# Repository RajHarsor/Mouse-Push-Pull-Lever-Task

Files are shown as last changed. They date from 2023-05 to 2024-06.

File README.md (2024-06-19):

# Getting Started

For learning how to start up a task with a already made box, please visit the [Getting Started](https://github.com/RajHarsor/Mouse-Push-Pull-Lever-Task/wiki/Getting-Started) page on the wiki.

# Contact
For any questions or concerns, please contact Raj Harsora at rdh92@scarletmail.rutgers.edu

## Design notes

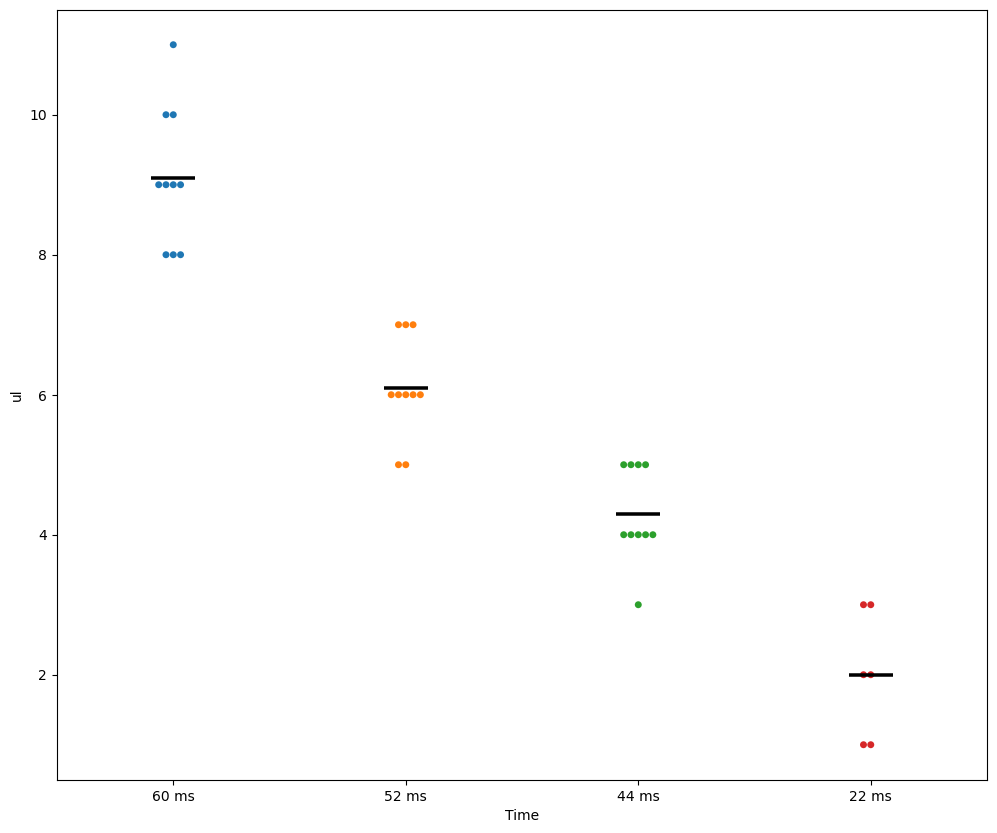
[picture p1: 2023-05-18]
Solenoid Equation Calculations/Figures/Figure.png

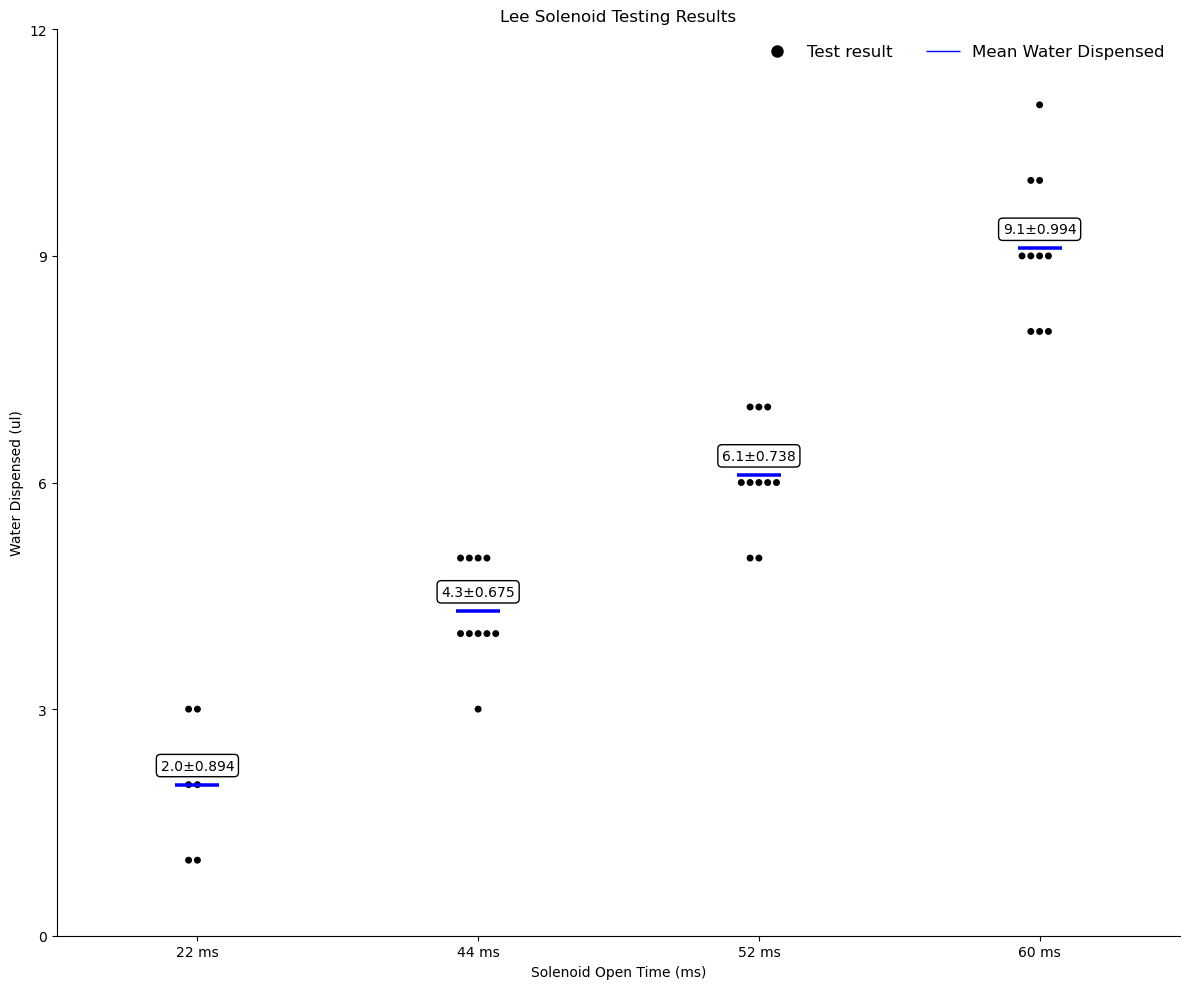
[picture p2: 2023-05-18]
Solenoid Equation Calculations/Figures/SolenoidFigure.png

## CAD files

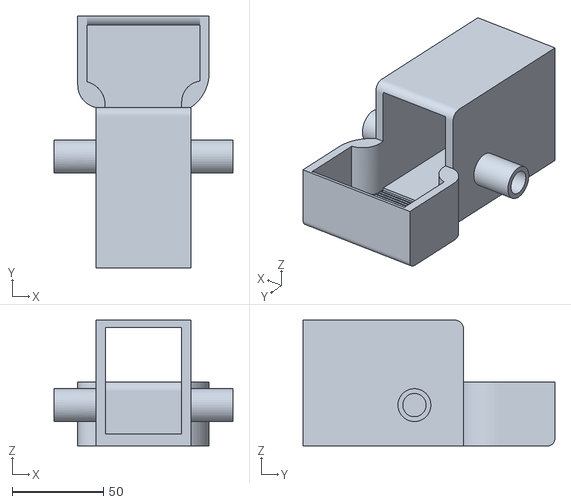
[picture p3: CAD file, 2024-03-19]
3D Print Files/MouseHolderCup.stl
98.1 x 138.0 x 69.0

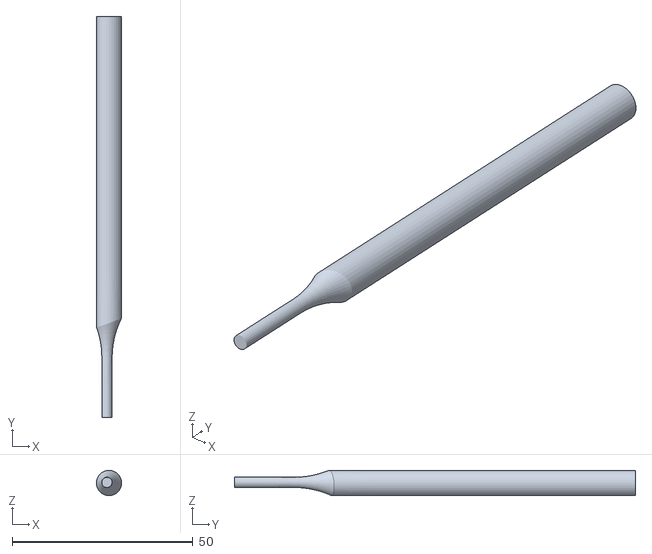
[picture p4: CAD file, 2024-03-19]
3D Print Files/LeverNew.stl
6.99 x 111.0 x 6.99

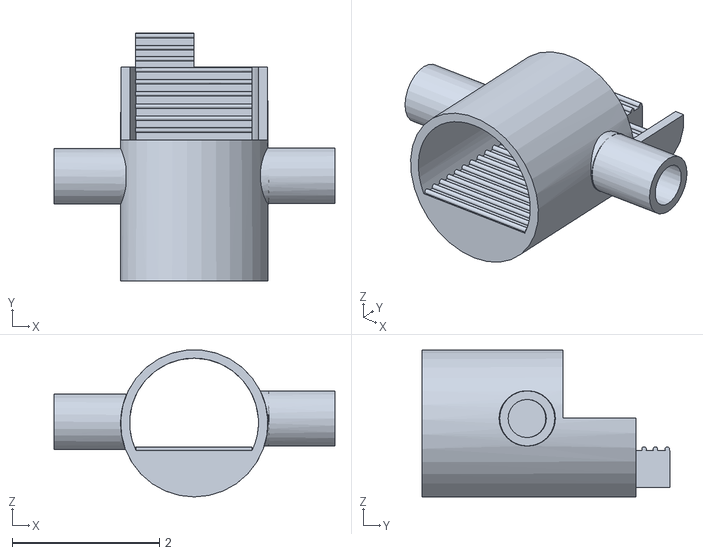
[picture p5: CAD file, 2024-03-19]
3D Print Files/Short mouse tube with open top - left.stl
3.82 x 3.37 x 2.00

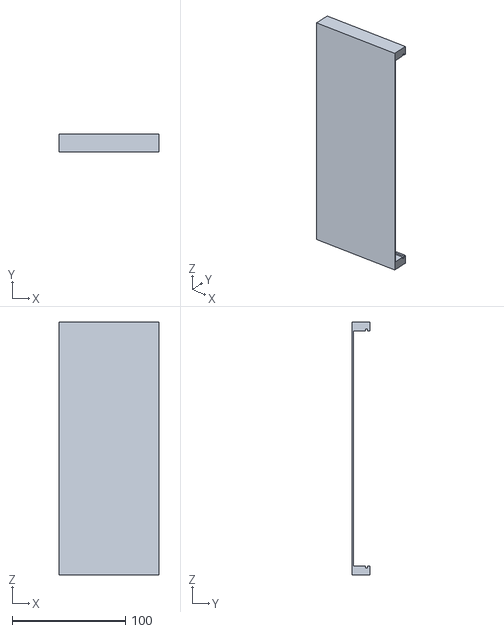
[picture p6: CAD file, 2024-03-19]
3D Print Files/Treedix Light Matrix Holder v2.stl
88.5 x 15.5 x 223.0

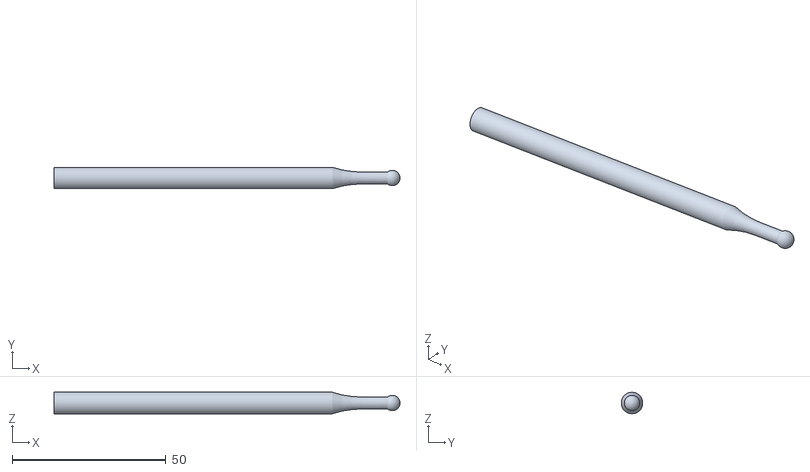
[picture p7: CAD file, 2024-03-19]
3D Print Files/Stick.stl
112.5 x 6.99 x 7.00

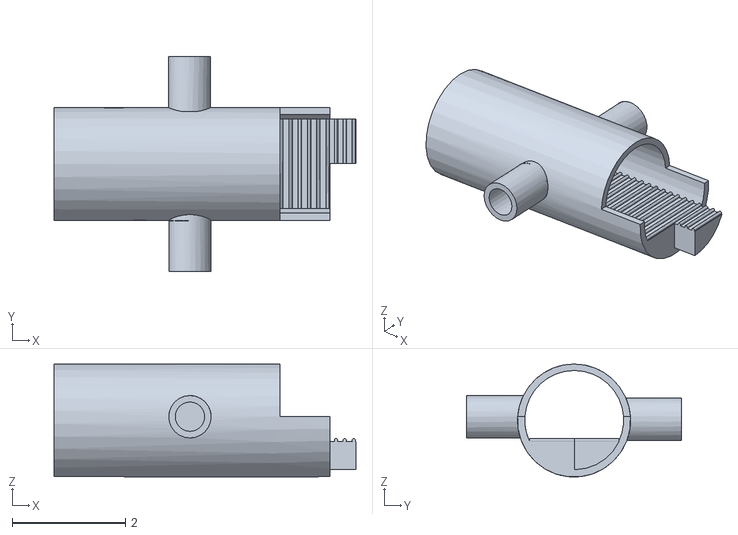
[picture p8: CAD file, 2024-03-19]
3D Print Files/Long mouse tube with open top - left.stl
5.34 x 3.80 x 2.00

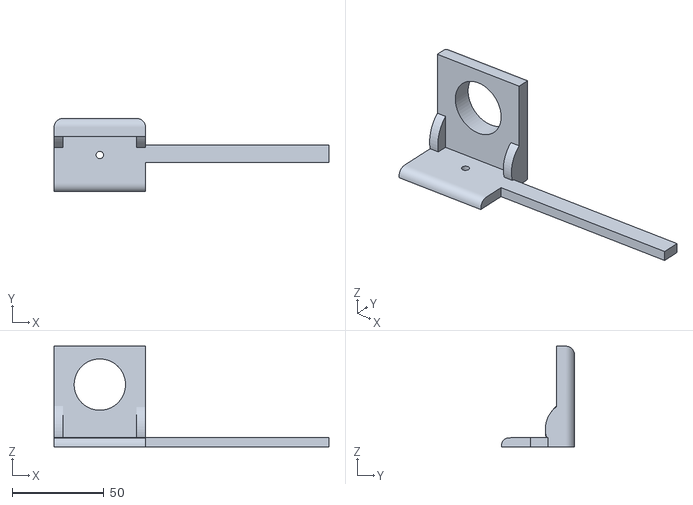
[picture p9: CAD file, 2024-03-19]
3D Print Files/JoystickReelHolder.stl
150.0 x 40.0 x 55.0

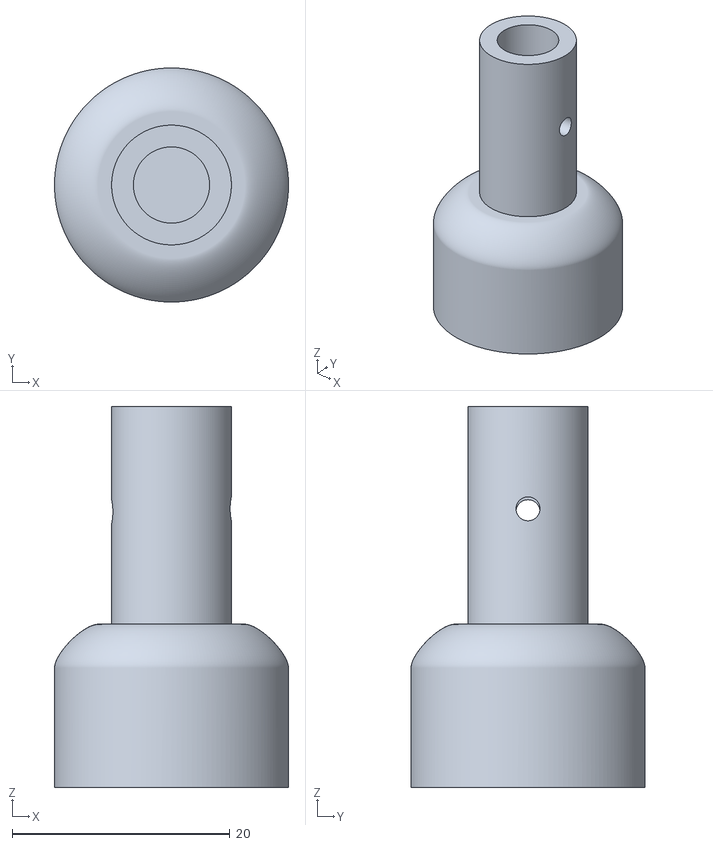
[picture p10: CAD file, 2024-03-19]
3D Print Files/Stick holder.stl
21.5 x 21.5 x 35.0

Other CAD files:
3D Print Files/LeverNew.f3d
3D Print Files/MouseHolderCup.f3d
3D Print Files/Treedix Light Matrix Holder v2.f3d

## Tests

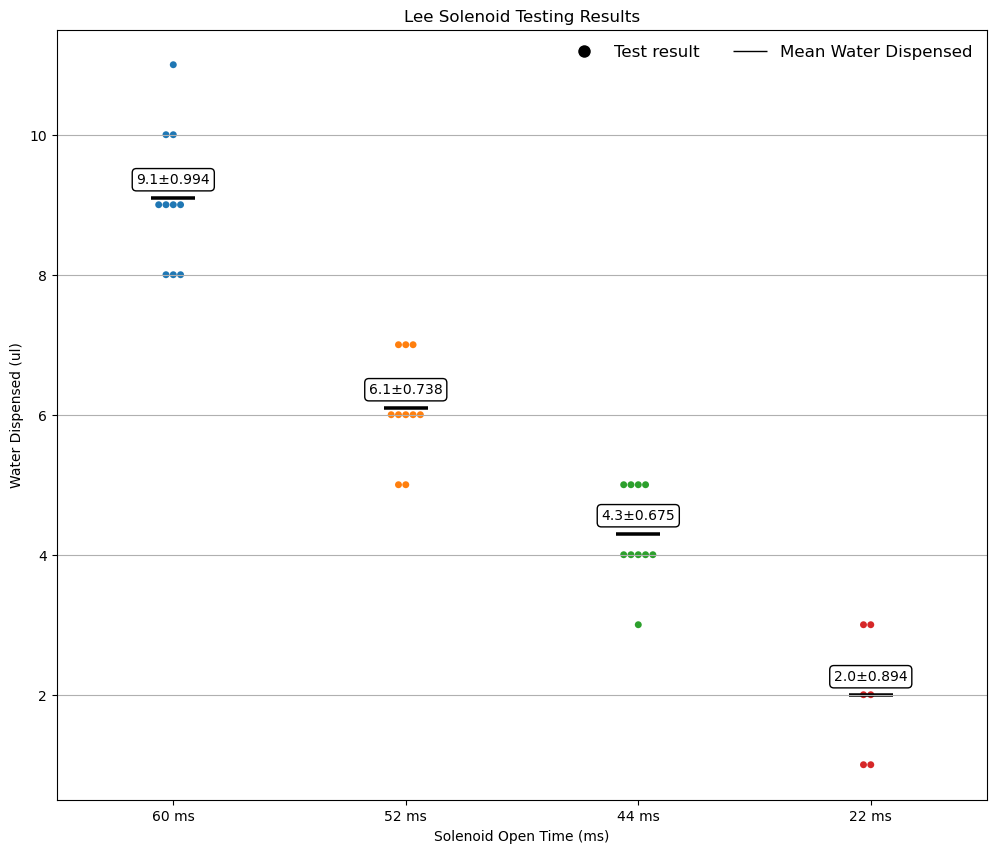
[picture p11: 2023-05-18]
Solenoid Equation Calculations/Figures/LeeSolenoidTestingFigureFinal.png

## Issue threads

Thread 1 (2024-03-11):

Adding button for water dispensing

RajHarsor, 2024-03-11:
To ensure a mouse gets water in the first movement, the tube must be completely filled up. Right now, this is a manual process. A button with an [attachInturrept()](https://www.arduino.cc/reference/en/language/functions/external-interrupts/attachinterrupt/) should be configured within the code to open the solenoid upon the button being pressed.

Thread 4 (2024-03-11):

Fix lick sensor

RajHarsor, 2024-03-11:
I had it working at one point but then it broke. Also, the speed is not the best (according to Masashi) and therefore, we might need to get another faster one and hook it up.

RajHarsor, 2024-05-08:
Temp fix _sometimes_ is simply reuploading the Joystick Code

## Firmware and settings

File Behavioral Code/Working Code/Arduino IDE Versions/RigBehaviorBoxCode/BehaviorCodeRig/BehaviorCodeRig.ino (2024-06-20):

/* #region DEPENDENCIES*/
#include <Arduino.h>
#include <vector>
#include <string>
#include <map>
#include <FastLED.h>
#include "parse_scripts.h"
#include "light_configs.h"
#include "solenoid_open_time.h"
#include "hold_time_mod_visual.h"
#include "hold_time_visual_punishment.h"
#include "reaction_time_mod_visual.h"
#include "WN_punishment.h"
#include "punishment_time_visual_mod.h"
#include "isi_delay_mod_visual.h"
#include "cue_evoked_sound.h"

/* #endregion */

/* #region PIN SETUPS */
#define VRX_PIN A0   // Arduino pin connected to VRX pin (aka Analog Pin A0), this is the blue cable
#define VRY_PIN A1   // Arduino pin connected to VRY pin (aka Analog Pin A1), this is the red cable
#define Solenoid 4   // Water Solenoid will be connected to Digital Pin 4
#define Puff 10      // Air solenoid for blowing air in the face of the mouse will be connected to Pin 5
#define REST_PIN 33  // Rest Pin will be connected to Digital Pin 33 on Behavior Teensy and Coordinate Teensy
#define PUSH_PIN 34  // Push Pin will be connected to Digital Pin 34 on Behavior Teensy and Coordinate Teensy
#define PULL_PIN 35  // Pull Pin will be connected to Digital Pin 35 on Behavior Teensy and Coordinate Teensy
/* #endregion */

/* #region LED Array Set Up*/
//Parameters
#define NUM_LEDS 48  //number of LEDs total
#define BRIGHTNESS 1

// Set up
#define DATA_PIN 8
#define CLOCK_PIN 14
//#define NUM_LEDS 48  //number of LEDs total
#define NUM_LEDS 64 //for the 8x8 matrix

CRGB leds[NUM_LEDS];  //define the array of LEDs

/* Array Set up (WS2012B) 48 LEDs

0  1  2  3  4  5
6  7  8  9  10 11
12 13 14 15 16 17
18 19 20 21 22 23
24 25 26 27 28 29
30 31 32 33 34 35
36 37 38 39 40 41
42 43 44 45 46 47
*/

/* #endregion */

/* #region BEHAVIOR VARIBALES CONST */
int totalTrials = 1000000;
int trialNumber = 1;
int decision;
int positionA = 0;
int positionB = 0;
int CorrectCounter = 0;
int SOpenTime1;

/* #endregion */

/* #region Timer Variables */
unsigned long currentMillis = 0;
int reactionTime;
#define timerMillis millis() - currentMillis
unsigned long startTime;

/* #endregion */

void setup() {
  delay(2000);
  /* #region Pins + Serial */
  Serial.begin(115200);
  Serial1.begin(9600);
  pinMode(Solenoid, OUTPUT);
  pinMode(Puff, OUTPUT);      // Sets the puff pin as an output
  pinMode(29, OUTPUT);        // Sets pin 29 as an output, if this pin is high it prints on the Coordinate Teensy that the current state is the rest state
  pinMode(30, OUTPUT);        // Sets pin 30 as an output, if this pin is high it prints on the Coordinate Teensy that the current state is the push/pull or push/down state
  pinMode(31, OUTPUT);        // Sets pin 31 as an output, if this pin is high it prints on the Coordinate Teensy that the current state is that the solenoid is open
  pinMode(32, OUTPUT);        // Sets pin 32 as an output, if this pin is high it prints on the Coordinate Teensy that the current state is that the ISI delay is occurring
  pinMode(28, OUTPUT);        // Set pin 28 as an output, if this pin is high it prints on the Coordinate Teensy that the current state is punishment
  pinMode(25, OUTPUT);
  pinMode(REST_PIN, INPUT);                             // Sets the rest pin as an input, if the mouse is in the rest coordinate range, the coordinate Teensy will set this pin high to tell the Behavior Teensy
  pinMode(PULL_PIN, INPUT);                             // Sets the pull pin as an input, if the mouse is in the pull coordinate range, the coordinate Teensy will set this pin high to tell the Behavior Teensy
  pinMode(PUSH_PIN, INPUT);                             // Sets the push pin as an input, if the mouse is in the push coordinate range, the coordinate Teensy will set this pin high to tell the Behavior Teensy                          // Probably useless
  randomSeed(analogRead(9));                            // Needed for random number generator for ISI Delay
  FastLED.addLeds<NEOPIXEL, DATA_PIN>(leds, NUM_LEDS);  // Sets up the light array
  FastLED.setBrightness(BRIGHTNESS);                    // Sets the brightness of the light array
  /* #endregion */
  Serial.println("What type of program would you like?");
  Serial.println("Type 1 for Visual Task");
  Serial.println("Type 2 for Auditory Task");
  parseProgramTypeInput();
  Serial.print(programType);
  switch (programType) {
    case 1: // visual task
      Serial.println("Pick the Stage (1-4)");
      parseVisualStage();
      break;
    case 2:
      Serial.println("What type of Motor Task do you want to do?");
      Serial.println("Type 1 for Cue-Evoked Task (Preset)");
      Serial.println("Type 2 for Cue-Evoked Task (Custom)");
      Serial.println("Type 3 for Single Direction Optogenetic Task");
      parseMotorTaskType();
      break;
  }
}

void loop() {
    // Rest position block
    currentMillis = millis();
    digitalWrite(29, HIGH);
    if (programType == 1) {
      holdTimeVisualTask();
    }
    while (timerMillis <= holdTime) {
      if (digitalRead(REST_PIN) == HIGH) {
        continue;
      } else {
        if (programType == 1) {
          holdTimeVisualPunishment();
        }
        currentMillis = millis();
        continue;
      }
    }
    digitalWrite(29, LOW);   // Tells the coordinate Teensy that the current state is not the rest state anymore
    digitalWrite(30, HIGH);  // Tells the coordinate Teensy that the current state is the push/pull or push/down state
    if (programType == 1) {
      reactionTimeWindowModVisual(); // modify the reaction time window if necessary
      lightArrayModifier(); // modify the percentages of light array options
      turnOnTheLights(); // turn on the appropriate light array
      digitalWrite(18, HIGH);
      }
    if (programType == 2) {
      play12kHzSound(soundCueDuration);
    }
    if (digitalRead(REST_PIN) != HIGH) {
      loop();
    }
    currentMillis = millis(); // start the reaction time window timer
    startTime = millis(); // start the reaction time timer
    while (timerMillis <= timeOutTime) {
      if (digitalRead(PUSH_PIN) == HIGH) {
          decision = 1; // push
          break;
        }
      if (digitalRead(PULL_PIN) == HIGH) {
          decision = 2; // pull
          break;
        } else {
          decision = 0; // punishment
        }
    }
    reactionTime = millis() - startTime; // calculate the reaction time
    lightsOff(); // turn off the lights - this can be in the motor task as well (doesn't hurt)
    digitalWrite(18, LOW);
    digitalWrite(30, LOW);  // Tells the coordinate Teensy that the current state is not the push/pull or push/down state anymore
    // Decision Results block //
    /* #region Visual Task Rewards */
    if (programType == 1) {
      switch (visualStage) {
        case 1:
          if (decision == 1) {
            positionA++;
            digitalWrite(31, HIGH);
            digitalWrite(Solenoid, HIGH);
            solenoidOpenTime();
            digitalWrite(Solenoid, LOW);
            digitalWrite(31, LOW);
            break;
          }
          if (decision == 2) {
            digitalWrite(31, HIGH);
            positionB++;
            digitalWrite(Solenoid, HIGH);
            solenoidOpenTime();
            digitalWrite(Solenoid, LOW);
            digitalWrite(31, LOW);
            break;
          }
        case 2:
          if (decision == 1 && lightDecision == 1) {
              correctSOpen(SOpenTime);
            } else if (decision == 2 && lightDecision == 2) {
              correctSOpen(SOpenTime);
            } else if ((decision == 1 || decision == 2) && lightDecision == 0) {
              correctSOpen(SOpenTime);
            } else {
              decision = 0;
            }
          break;
        case 3:
          if (decision == 1 && lightDecision == 1) {
              float ratio = (float)reactionTime / (float)timeOutTime;
              SOpenTime1 = -37.5 * (ratio) + 55.75;
              correctSOpen(SOpenTime1);
          } else if (decision == 2 && lightDecision == 2) {
              float ratio = (float)reactionTime / (float)timeOutTime;
              SOpenTime1 = -37.5 * (ratio) + 55.75;
              correctSOpen(SOpenTime1);
          } else if ((decision == 1 || decision == 2) && lightDecision == 0) {
              float ratio = (float)reactionTime / (float)timeOutTime;
              SOpenTime1 = -37.5 * (ratio) + 55.75;
              correctSOpen(SOpenTime1);
          } else {
            decision = 0;
          }
          break;
        case 4:
          if (decision == 1 && lightDecision == 1) {
            correctSOpen(SOpenTime);
          } else if (decision == 2 && lightDecision == 2) {
            correctSOpen(SOpenTime);
          } else if ((decision == 1 || decision == 2) && lightDecision == 0) {
            correctSOpen(SOpenTime);
          } else {
            decision = 0;
          }
          break;
      }
    }
    /* #endregion */
    /* #region Rewards for Cue Evoked Task */
    if (motorTaskType == 1) {
      switch (CueEvokedTaskDay) {
        case 1:
          if (decision == 1) {
            correctSOpen(SOpenTime);
          } else {
            decision == 0;
          }
          break;
        case 2:
          if (decision == 1) {
            correctSOpen(SOpenTime);
          } else {
            decision == 0;
          }
          break;
        case 3:
          if (decision == 1) {
            positionA++;
            digitalWrite(31, HIGH);
            digitalWrite(Solenoid, HIGH);
            solenoidOpenTime();
            digitalWrite(Solenoid, LOW);
            digitalWrite(31, LOW);
            break;
          }
          if (decision == 2) {
            digitalWrite(31, HIGH);
            positionB++;
            digitalWrite(Solenoid, HIGH);
            solenoidOpenTime();
            digitalWrite(Solenoid, LOW);
            digitalWrite(31, LOW);
            break;
          }
      }
    }
    /* #endregion */
    // Punishment block //
    if (programType == 1 && decision == 0) {
      punishmentVisualTaskChooser();
    }
    if (motorTaskType == 1 && decision == 0) {
      wnPunishment(punishmentTime);
    }
    digitalWrite(28, LOW);
    // ISI Delay block //
    digitalWrite(32, HIGH);  // Tells the coordinate Teensy that the current state is that the ISI delay is occurring
    if (programType == 1) {
      isiDelayModVisual();
    }
    int isiDelay = random(isiDelayLowerRange, isiDelayUpperRange + 1);
    delay(isiDelay);
    digitalWrite(32, LOW);  // Tells the coordinate Teensy that the current state is not the ISI delay state anymore
    // Print the data and increment variables as needed //
    if (programType == 1) {
      printVisualInformation(isiDelay);
    }
    if (motorTaskType == 1) {
      printCueEvokedInformation(isiDelay);
    }
    trialNumber++;
    digitalWrite(37, HIGH);
    delay(2);
    digitalWrite(37, LOW);
}

/* #region CueEvokedTaskInformation */
void printCueEvokedInformation(int isiDelay) {
  switch (CueEvokedTaskDay) {
    case 1: case 2:
      Serial.print(trialNumber);
      Serial.print(" , ");
      Serial.print(reactionTime);
      Serial.print(" , ");
      printDecision();
      Serial.print(" , ");
      printCorrectStatusMotor();
      Serial.print(" , ");
      Serial.print (CorrectCounter);
      Serial.print(" / ");
      Serial.print(trialNumber);
      Serial.print(" , ");
      Serial.print(SOpenTime);
      Serial.print(" , ");
      Serial.print(isiDelay);
      Serial.print(" ; ");
      break;
    case 3:
      Serial.print(trialNumber);
      Serial.print(" , ");
      Serial.print(reactionTime);
      Serial.print(" , ");
      printDecision();
      Serial.print(" , ");
      printCorrectStatusMotor();
      Serial.print(" , ");
      Serial.print (CorrectCounter);
      Serial.print(" / ");
      Serial.print(trialNumber);
      Serial.print(" , ");
      Serial.print(OpenTime);
      Serial.print(" , ");
      Serial.print(positionA);
      Serial.print(" / ");
      Serial.print(positionB);
      Serial.print(" , ");
      Serial.print(isiDelay);
      Serial.print(" ; ");
      break;
  }
}
/* #endregion */


/* #region Visual Task Print Statements*/
void printVisualInformation(int isiDelay) {
  switch (visualStage) {
    case 1:
      Serial.print(trialNumber);
      Serial.print(" , ");
      Serial.print(reactionTime);
      Serial.print(" , ");
      printLightDecision();
      Serial.print(" , ");
      printDecision();
      Serial.print(" , ");
      printCorrectStatus();
      Serial.print(" , ");
      Serial.print (CorrectCounter);
      Serial.print(" / ");
      Serial.print(trialNumber);
      Serial.print(" , ");
      printOpenTime();
      Serial.print(" , ");
      Serial.print(positionA);
      Serial.print(" / ");
      Serial.print(positionB);
      Serial.print(" , ");
      Serial.print(isiDelay);
      Serial.print(" , ");
      // debug //
      Serial.print( " // ");
      Serial.print(" , ");
      Serial.print(holdTime);
      Serial.print(" , ");
      Serial.print(timeOutTime);
      Serial.print(" , ");
      Serial.print(punishmentTime);
      Serial.print(" , ");
      Serial.print(isiDelayLowerRange);
      Serial.print(" , ");
      Serial.print(isiDelayUpperRange);
      Serial.println(" ; ");
      break;
    case 2:
      Serial.print(trialNumber);
      Serial.print(" , ");
      Serial.print(reactionTime);
      Serial.print(" , ");
      printLightDecision();
      Serial.print(" , ");
      printDecision();
      Serial.print(" , ");
      printCorrectStatus();
      Serial.print(" , ");
      Serial.print (CorrectCounter);
      Serial.print(" / ");
      Serial.print(trialNumber);
      Serial.print(" , ");
      printOpenTime();
      Serial.print(" , ");
      Serial.print(isiDelay);
      Serial.print(" , ");
      // debug //
      Serial.print( " // ");
      Serial.print(" , ");
      Serial.print(plusPercentage);
      Serial.print(" , ");
      Serial.print(lightsVerticalPercentage);
      Serial.print(" , ");
      Serial.print(lightsHorizontalPercentage);
      Serial.print(" , ");
      Serial.print(holdTime);
      Serial.print(" , ");
      Serial.print(timeOutTime);
      Serial.print(" , ");
      Serial.print(punishmentTime);
      Serial.print(" , ");
      Serial.print(isiDelayLowerRange);
      Serial.print(" , ");
      Serial.print(isiDelayUpperRange);
      Serial.println(" ; ");
      break;
    case 3:
      Serial.print(trialNumber);
      Serial.print(" , ");
      Serial.print(reactionTime);
      Serial.print(" , ");
      printLightDecision();
      Serial.print(" , ");
      printDecision();
      Serial.print(" , ");
      printCorrectStatus();
      Serial.print(" , ");
      Serial.print (CorrectCounter);
      Serial.print(" / ");
      Serial.print(trialNumber);
      Serial.print(" , ");
      printOpenTime();
      Serial.print(" , ");
      Serial.print(isiDelay);
      Serial.print(" , ");
      // debug //
      Serial.print( " // ");
      Serial.print(" , ");
      Serial.print(plusPercentage);
      Serial.print(" , ");
      Serial.print(lightsVerticalPercentage);
      Serial.print(" , ");
      Serial.print(lightsHorizontalPercentage);
      Serial.print(" , ");
      Serial.print(holdTime);
      Serial.print(" , ");
      Serial.print(timeOutTime);
      Serial.print(" , ");
      Serial.print(punishmentTime);
      Serial.print(" , ");
      Serial.print(isiDelayLowerRange);
      Serial.print(" , ");
      Serial.print(isiDelayUpperRange);
      Serial.println(" ; ");
      break;
    case 4:
      Serial.print(trialNumber);
      Serial.print(" , ");
      Serial.print(reactionTime);
      Serial.print(" , ");
      printLightDecision();
      Serial.print(" , ");
      printDecision();
      Serial.print(" , ");
      printCorrectStatus();
      Serial.print(" , ");
      Serial.print (CorrectCounter);
      Serial.print(" / ");
      Serial.print(trialNumber);
      Serial.print(" , ");
      printOpenTime();
      Serial.print(" , ");
      Serial.print(isiDelay);
      Serial.print(" , ");
      // debug //
      Serial.print( " // ");
      Serial.print(" , ");
      Serial.print(plusPercentage);
      Serial.print(" , ");
      Serial.print(lightsVerticalPercentage);
      Serial.print(" , ");
      Serial.print(lightsHorizontalPercentage);
      Serial.print(" , ");
      Serial.print(holdTime);
      Serial.print(" , ");
      Serial.print(timeOutTime);
      Serial.print(" , ");
      Serial.print(punishmentTime);
      Serial.print(" , ");
      Serial.print(isiDelayLowerRange);
      Serial.print(" , ");
      Serial.print(isiDelayUpperRange);
      Serial.println(" ; ");
      break;
  }
}

void correctSOpen(int var) {
  digitalWrite(31, HIGH);
  digitalWrite(Solenoid, HIGH);
  delay(var);
  digitalWrite(Solenoid, LOW);
  digitalWrite(31, LOW);
}


void printLightDecision() {
  if (lightDecision == 0){
    Serial.print("Plus");
  } else if (lightDecision == 1) {
    Serial.print("Vertical");
  } else if (lightDecision == 2) {
    Serial.print("Horizontal");
  }
}

void printDecision() {
  if (decision == 1) {
    Serial.print("Push");
  } else if (decision == 2) {
    Serial.print("Pull");
  } else if (decision == 0) {
    Serial.print("timedOut");
  }
}

void printCorrectStatus() {
  if (decision == 1 || decision == 2 && lightDecision == 0) {
    Serial.print("Correct");
    correct = true;
    CorrectCounter++;
  } else if (decision == 1 && lightDecision == 1) {
    Serial.print("Correct");
    correct = true;
    CorrectCounter++;
  } else if (decision == 2 && lightDecision == 2) {
    Serial.print("Correct");
    correct = true;
    CorrectCounter++;
  } else {
    Serial.print("Incorrect");
    correct = false;
  }
}

void printCorrectStatusMotor() {
  if (decision == 1 || decision == 2) {
    Serial.print("Correct");
    correct = true;
    CorrectCounter++;
  } else {
    Serial.print("Incorrect");
    correct = false;
  }
}
void printOpenTime() {
  switch (visualStage) {
    case 1:
      if (decision == 1 || decision == 2) {
        Serial.print(OpenTime);
      } else {
        Serial.print("0");
      }
      break;
    case 2: case 3: case 4:
      if (decision != 0) {
        Serial.print(SOpenTime);
      } else {
        Serial.print("0");
      }
      break;
}
}

/* #endregion */

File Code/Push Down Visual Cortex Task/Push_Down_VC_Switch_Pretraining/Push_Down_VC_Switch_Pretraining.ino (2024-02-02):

#include <Arduino.h>

/// Behavioral Testing Configuration ///
int totalTrials = 1000000;       // DO NOT TOUCH THIS
int isiDelayLowerRange;          // Enter ISI delay lower Value in ms
int isiDelayUpperRange;          // Enter ISI delay upper Value in ms
int timeOutTime;  // Enter the time out time
int trialNumber = 0;             // DO NOT TOUCH THIS
int decision;                    // decision parameter
// const int ArraySize = 6; // Make sure this is an even number
int solenoidDelayRight = 44;  // Enter the solenoid open time in ms
int lightArrayRandomizer;

/// Pin Set-Ups ///
#define VRX_PIN A0   // Arduino pin connected to VRX pin (aka Analog Pin A0), this is the blue cable
#define VRY_PIN A1   // Arduino pin connected to VRY pin (aka Analog Pin A1), this is the red cable
#define Solenoid 4   // Water Solenoid will be connected to Digital Pin 4
#define Puff 10      // Air solenoid for blowing air in the face of the mouse will be connected to Pin 5
#define REST_PIN 33  // Rest Pin will be connected to Digital Pin 33 on Behavior Teensy and Coordinate Teensy
#define PUSH_PIN 34  // Push Pin will be connected to Digital Pin 34 on Behavior Teensy and Coordinate Teensy
#define PULL_PIN 35  // Pull Pin will be connected to Digital Pin 35 on Behavior Teensy and Coordinate Teensy

/// Soundboard Set-up ///
#include <Adafruit_Soundboard.h>

// Choose any two pins that can be used with SoftwareSerial to RX & TX
// #define SFX_TX 5
// #define SFX_RX 6


// Connect to the RST pin on the Sound Board
#define SFX_RST 19

// Hardware Serial Communication Set Up
Adafruit_Soundboard sfx = Adafruit_Soundboard(&Serial1, NULL, SFX_RST);

/// Timer Variables ///
#define timerMillis millis() - currentMillis
unsigned long currentMillis = 0;
unsigned long reactionTime;
unsigned long startTime;

/// Light Array Setup ///

#include <FastLED.h>

//Parameters
#define NUM_LEDS 48  //number of LEDs total
#define BRIGHTNESS 64

//Set up
#define DATA_PIN 8
#define CLOCK_PIN 14
CRGB leds[NUM_LEDS];  //define the array of LEDs

/* Array Set up (WS2012B)

0  1  2  3  4  5
6  7  8  9  10 11
12 13 14 15 16 17
18 19 20 21 22 23
24 25 26 27 28 29
30 31 32 33 34 35
36 37 38 39 40 41
42 43 44 45 46 47

*/


void setup() {
  Serial.begin(115200);
  Serial1.begin(9600);
  pinMode(Solenoid, OUTPUT);  // Sets the solenoid pin as an output
  pinMode(Puff, OUTPUT);      // Sets the puff pin as an output
  pinMode(29, OUTPUT);        // Sets pin 29 as an output, if this pin is high it prints on the Coordinate Teensy that the current state is the rest state
  pinMode(30, OUTPUT);        // Sets pin 30 as an output, if this pin is high it prints on the Coordinate Teensy that the current state is the push/pull state
  pinMode(31, OUTPUT);        // Sets pin 31 as an output, if this pin is high it prints on the Coordinate Teensy that the current state is that the solenoid is open
  pinMode(32, OUTPUT);        // Sets pin 32 as an output, if this pin is high it prints on the Coordinate Teensy that the current state is that the ISI delay is occurring
  pinMode(28, OUTPUT);        // Set pin 28 as an output, if this pin is high it prints on the Coordinate Teensy that the current state is punishment
  pinMode(25, OUTPUT);
  pinMode(REST_PIN, INPUT);                             // Sets the rest pin as an input, if the mouse is in the rest coordinate range, the coordinate Teensy will set this pin high to tell the Behavior Teensy
  pinMode(PULL_PIN, INPUT);                             // Sets the pull pin as an input, if the mouse is in the pull coordinate range, the coordinate Teensy will set this pin high to tell the Behavior Teensy
  pinMode(PUSH_PIN, INPUT);                             // Sets the push pin as an input, if the mouse is in the push coordinate range, the coordinate Teensy will set this pin high to tell the Behavior Teensy                          // Probably useless
  randomSeed(analogRead(9));                            // Needed for random number generator for ISI Delay
  FastLED.addLeds<NEOPIXEL, DATA_PIN>(leds, NUM_LEDS);  // Sets up the light array
  FastLED.setBrightness(BRIGHTNESS);
  Serial.print("Behavior");
  parseInput();
  // Serial.println("Input parsed");
}

void loop() {
  for (trialNumber = 1; trialNumber < totalTrials; trialNumber++) {
    // Block 1 - Rest State (wait for 50 ms in the rest position)
    currentMillis = millis();  // starts the timber
    digitalWrite(29, HIGH);    //Tells the coordinate Teensy that the current state is the rest state
    // Serial.println("In Rest");
    while (timerMillis <= 50) {
      if (digitalRead(REST_PIN) == HIGH) {
        continue;
      } else {
        currentMillis = millis();
        continue;
      }
    }
    digitalWrite(29, LOW);   // Tells the coordinate Teensy that the current state is not the rest state anymore
    digitalWrite(30, HIGH);  // Tells the coordinate Teensy that the current state is the push/down state (decision making state)
    // Block 2 - Push/Pull State (light array decision)
    lightArrayPlus();
    // Block 3 Mouse Decision Making
    currentMillis = millis(); // timer for timeout
    startTime = millis(); // timer for reaction time
    while (timerMillis <= timeOutTime) {
      if (digitalRead(PUSH_PIN) == HIGH) {
        decision = 1;
        break;
      } else if (digitalRead(PULL_PIN) == HIGH) {
        decision = 2;
        break;
      } else {
        decision = 0;
      }
    }
    // Block 4 Decision Results
    switch (decision) {
      case 1:
        plusCorrectPush();
        break;
      case 2:
        plusCorrectPull();
        break;
      case 0:
        timeout();
    }
    lightsOff();
    digitalWrite(32, HIGH);  // Tells the coordinate teensy the current state is that the ISI delay is occurring
    int isiDelay = random(isiDelayLowerRange, isiDelayUpperRange + 1);  // Generates a random number between the lower and upper range of the ISI delay
    currentMillis = millis();
    Serial.print(" , ");
    Serial.print(isiDelay);
    Serial.println(" ; ");
    while (timerMillis <= isiDelay) {  //ISI delay
      continue;
    }
    // Serial.print("ISI Delay = "); // Prints the ISI delay
    digitalWrite(32, LOW);  // Tells the coordinate teensy the ISI delay state is ended
  }
}


/// Parse Input Function for user inputs ///
void parseInput() {
  while (!Serial.available()) {
  }

  String input = Serial.readStringUntil('\n');
  int numValues = sscanf(input.c_str(), "%d, %d, %d", &isiDelayLowerRange, &isiDelayUpperRange, &timeOutTime);
}

/// Solenoid Open Time Function ///

/// Light Array Functions ///

// Plus Sign //
void lightArrayPlus() {
  for (int i = 8; i <= 32; i = i + 6) {
    leds[i] = CRGB::Blue;
    FastLED.show();
  }

  for (int i = 18; i <= 22; i++) {
    leds[i] = CRGB::Blue;
    FastLED.show();
  }

}
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

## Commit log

2023-06-19 fixing commits
    [BehaviorBoxCircuitfzz.fzz]
2023-06-27 changed behavior code for accurate print statement
2023-07-12 Added Structure Assembly Pictures
2023-07-13 Added some structure assembly steps
2024-01-01 did a lot of work
    [total_trials_stats.csv]
2024-01-02 started comparitive analysis
    [ratio_stats.csv]
2024-01-04 Update pin names and coordinates in code
2024-01-10 added rt analysis (currently working on)
    [ratio_stats.csv, total_trials_stats.csv]
2024-01-16 Update push/pull state and add solenoid open time function
2024-01-29 pushdown VS switch is the correct version
2024-02-01 moved around location of printing reaction time to be consistent with other paradigms
2024-02-01 added punishment signal to coordinate teensy
2024-02-05 fixed arduino configs
2024-02-08 finished + tested stage 1
2024-02-08 finished stage 2
2024-02-19 trying to make the motor code work
2024-02-19 cue evoked print information
2024-02-27 confirmed everything script works - set up for stage 1a
2024-03-01 fixed a print statement
2024-03-07 changed things for stage 1b
2024-03-12 Added 3D print files
    [JoystickReelHolder.stl, LeverNew.f3d, LeverNew.stl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]
2024-03-12 Added Treedix light matrix
    [Treedix Light Matrix Holder v2.f3d, Treedix Light Matrix Holder v2.stl]
2024-03-20 making some changes for the LED configs for the 64 LED Matrix
2024-03-21 made a light configuration for the plus symbol for neopixel LED matricies
2024-03-22 fixed something related to water if array is max
    [solenoid_open_time.cpp]
2024-03-25 fixed some things for day 1
    [solenoid_open_time.cpp]
2024-03-27 solenoid times change
2024-05-06 added combined coordinate code arduino version
2024-06-19 added PCB Design
    [BehaviorBoxCircuitfzz.fzz, BehavioralBoxSchematic_Final.fzz]
